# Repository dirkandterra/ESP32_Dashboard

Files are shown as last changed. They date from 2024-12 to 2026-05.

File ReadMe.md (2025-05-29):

# _ESP_Dashboard_  

_This project uses the a CANBus and an ESP32 to drive a 2004 Dodge Intrepid Dashboard._

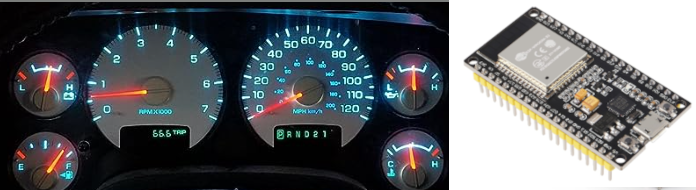
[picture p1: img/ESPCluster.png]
  

## How to use  

### Hardware Required  
* 2004 Dodge Intrepid Instrument Panel
* Connection:  

| Signal | Intrepid  | ESP32 |
|---|---|---|
| 5V | 5V		|  5V |
| GLDATA | GLDATA	|  D13  |
| GLCLK | GLCLK 	|  D14  |
| LightLatch| LightLatch|  D6 |
| Gauge CS  | Gauge CS  |  D7 |
| VFDDATA | VFDDATA |  D13  |
| VFDCLK	| VFDCLK	|  D14  |
| VFD Pls	| VFD Pls	|  D12  |
| Backlight | UC_LMP_DRV|  D15  |
| PB Input  | ODO PB |  D0 |
| L Turn | C2-5		|  D21  |
| R Turn | C1-8 |  D22  |
| HighBeam  | C1-10 |  D23  |
| OilPress  | C2-10 |  D2 |
| ABS		| ??		|  D18  |
| Airbag | ??		|  D19  |
| GND | GND |  GND  |
| CAN TX |			|  D5	|
| CAN RX	|			|  D4	|

### Arduino Library Needed  

```
https://github.com/coryjfowler/MCP_CAN_lib.git
```

* MCP_CAN_lib

### Intrepid Dashboard Help

* Board Files:
Board_Files 

* Intrepid Schematic (Not Complete):  

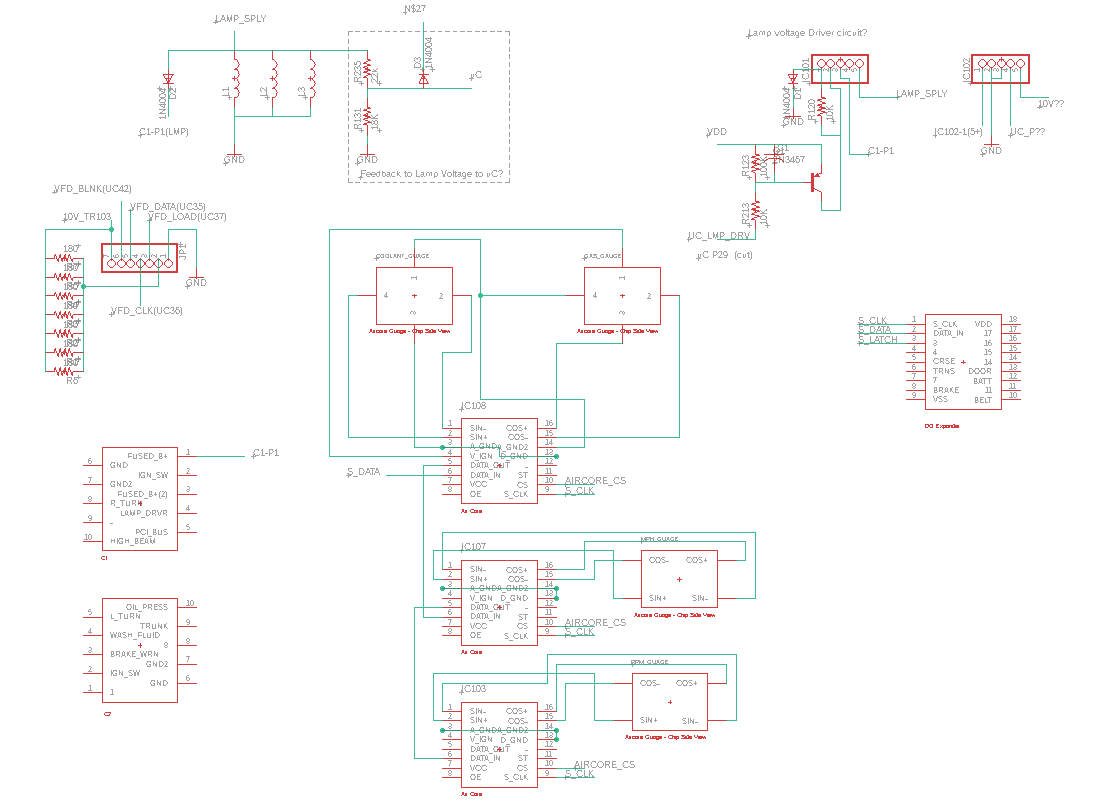
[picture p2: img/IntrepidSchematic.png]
IntrepidSchematic


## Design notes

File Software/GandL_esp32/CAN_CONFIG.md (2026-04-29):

# CAN Bus Gauge & VFD Configuration

Settings for each channel are stored in EEPROM and sent over the USB serial port (115200 baud). Switch the dashboard to **CAN mode** by pressing the mode button until the VFD shows `CAN`.

---

## Channel Assignments

| Channel | Output |
|---|---|
| 0 | Gauge 0 (e.g. RPM) |
| 1 | Gauge 1 (e.g. MPH) |
| 2 | Gauge 2 (e.g. Fuel) |
| 3 | Gauge 3 (e.g. Temp) |
| 4 | VFD numeric display |

---

## Config Fields

Each channel has six fields:

| Field | Size | Description |
|---|---|---|
| `PGN` | 3 bytes | Upper 3 bytes of the CAN ID (big-endian). Set a byte to `0xFF` to wildcard it. |
| `Source` | 1 byte | Lowest byte of the CAN ID (J1939 source address). Set to `0xFF` to match any. |
| `DataStart` | 1 byte | Index of the first data byte to read (0–7). |
| `DataLen` | 1 byte | Number of bytes to read (1–4). Data bytes are little-endian — `DataStart` is the LSB. |
| `Gain` | float | Multiplied against the raw extracted value. |
| `Offset` | float | Added after the gain multiplication. |

The final value sent to the gauge or VFD is:

```
result = raw * gain + offset
```

### Little-Endian Extraction

For a 2-byte signal at `DataStart=0` with frame bytes `[0xA0, 0x02, ...]`:

```
raw = 0xA0 + (0x02 << 8) = 0x02A0 = 672
```

---

## CAN ID Encoding

The four bytes `PGN[0]`, `PGN[1]`, `PGN[2]`, `Source` form a 32-bit CAN identifier (big-endian):

```
targetId = (PGN[0] << 24) | (PGN[1] << 16) | (PGN[2] << 8) | Source
```

**Standard 11-bit ID** (e.g. `0x1B0`):

```
PGN = 0001B0   src = FF
→ targetId = 0x000001B0 = 0x1B0  (source wildcarded)
```

**J1939 29-bit ID** (e.g. `0x18FEF100`):

```
PGN = 18FEF1   src = 00
→ targetId = 0x18FEF100
```

### Wildcards

Set any byte of PGN or src to `FF` to ignore it during matching.

```
PGN = 18FEF1   src = FF
→ matches 0x18FEF1xx (any source address)
```

---

## Serial Config Protocol

Send a comma-separated ASCII line terminated with `\r`. Works in any display mode.

```
C<ch>,<PGN>,<src>,<dataStart>,<dataLen>,<gain>,<offset>\r
```

- `PGN` — 6 hex digits (no prefix), upper-case or lower-case, e.g. `0000CF`
- `src` — 2 hex digits, e.g. `FF` for wildcard
- `dataStart`, `dataLen` — decimal integers
- `gain`, `offset` — floating point

```
C0,0000CF,FF,0,2,0.25,0.0\r
```

The device responds with a confirmation line, e.g.:

```
CFG ch0: PGN=0000CF src=FF dStart=0 dLen=2 gain=0.2500 off=0.0000
```

### Query a Channel

Send `Q` followed by the channel digit and `\r` to read back saved settings:

```
Q0\r   → prints channel 0 config
Q4\r   → prints channel 4 (VFD) config
```

---

## Examples

### RPM on ID 0x0CF, bytes 0–1 (little-endian)
Raw convention: `(byte1 << 8 | byte0) / 4 = RPM`

```
C0,0000CF,FF,0,2,0.25,0.0\r
```

### Vehicle Speed on ID 0x1B0, bytes 0–1 (little-endian)
Raw convention: `(byte1 << 8 | byte0) / 128 = MPH`

```
C1,0001B0,FF,0,2,0.0078125,0.0\r
```

### Coolant Temp on ID 0x1E4, byte 0 (single byte)
Raw convention: `byte0 - 40 = °C`, mapped to 0–100 gauge range (40–120 °C → 0–100%)

```
C3,0001E4,FF,0,1,1.25,-50.0\r
```

### VFD showing fuel level on ID 0x1E4, byte 1 (single byte)
Raw convention: 0–255 → 0–100%

```
C4,0001E4,FF,1,1,0.3922,0.0\r
```

---

## Discovering IDs

Set `CAN_SNIFF_MODE 1` in `CANDash.h` and monitor the serial output. Every received frame is printed:

```
CAN 0x000001B0 [8]: A0 02 00 00 00 00 00 00
```

This shows the full 32-bit identifier, data length, and all 8 data bytes in frame order (byte 0 first). Remember that multi-byte signals are little-endian — byte 0 is the LSB. In the example above, the 2-byte value at bytes 0–1 is `0x02A0 = 672`.

Set `CAN_SNIFF_MODE 0` when done to reduce serial traffic.

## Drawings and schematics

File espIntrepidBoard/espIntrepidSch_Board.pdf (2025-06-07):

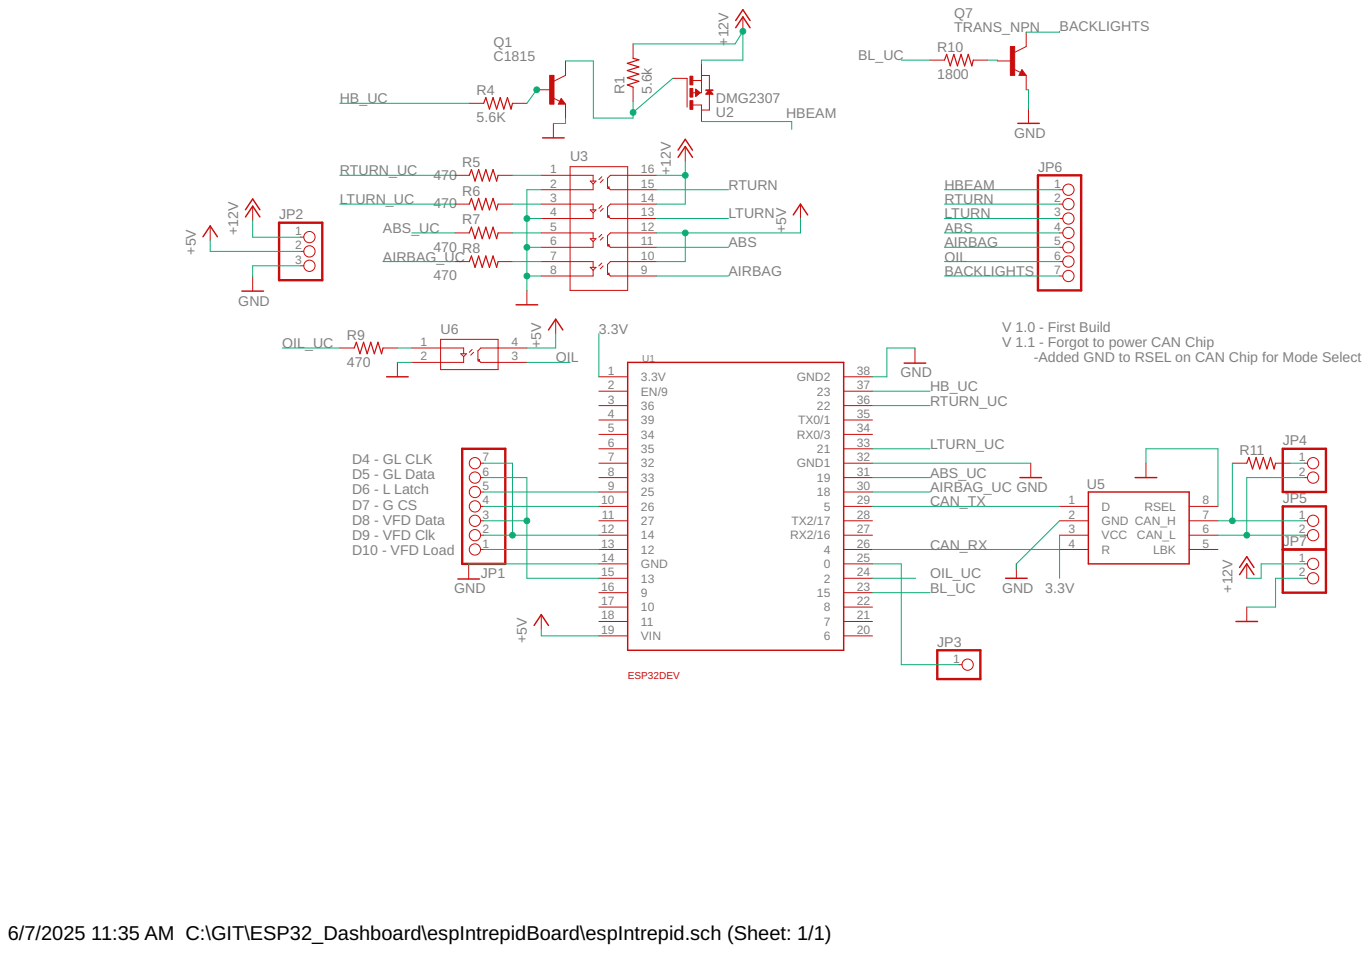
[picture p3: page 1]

V 1.0 - First Build
V 1.1 - Forgot to power CAN Chip
-Added GND to RSEL on CAN Chip for Mode Select

D8 - VFD Data D9 - VFD Clk

6/7/2025 11:35 AM C:\GIT\ESP32_Dashboard\espIntrepidBoard\espIntrepid.sch (Sheet: 1/1)

## ESP32_Dashboard

U1

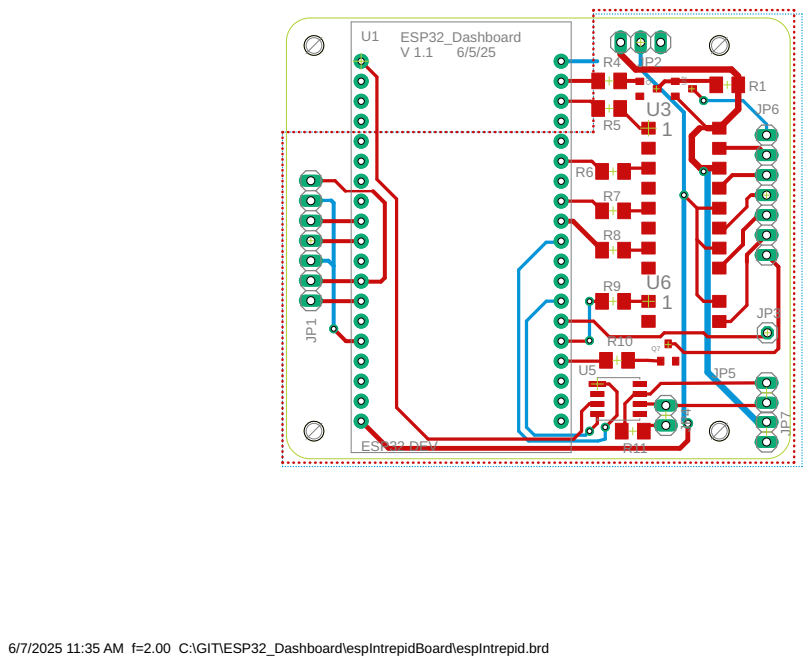
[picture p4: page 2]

6/7/2025 11:35 AM f=2.00 C:\GIT\ESP32_Dashboard\espIntrepidBoard\espIntrepid.brd

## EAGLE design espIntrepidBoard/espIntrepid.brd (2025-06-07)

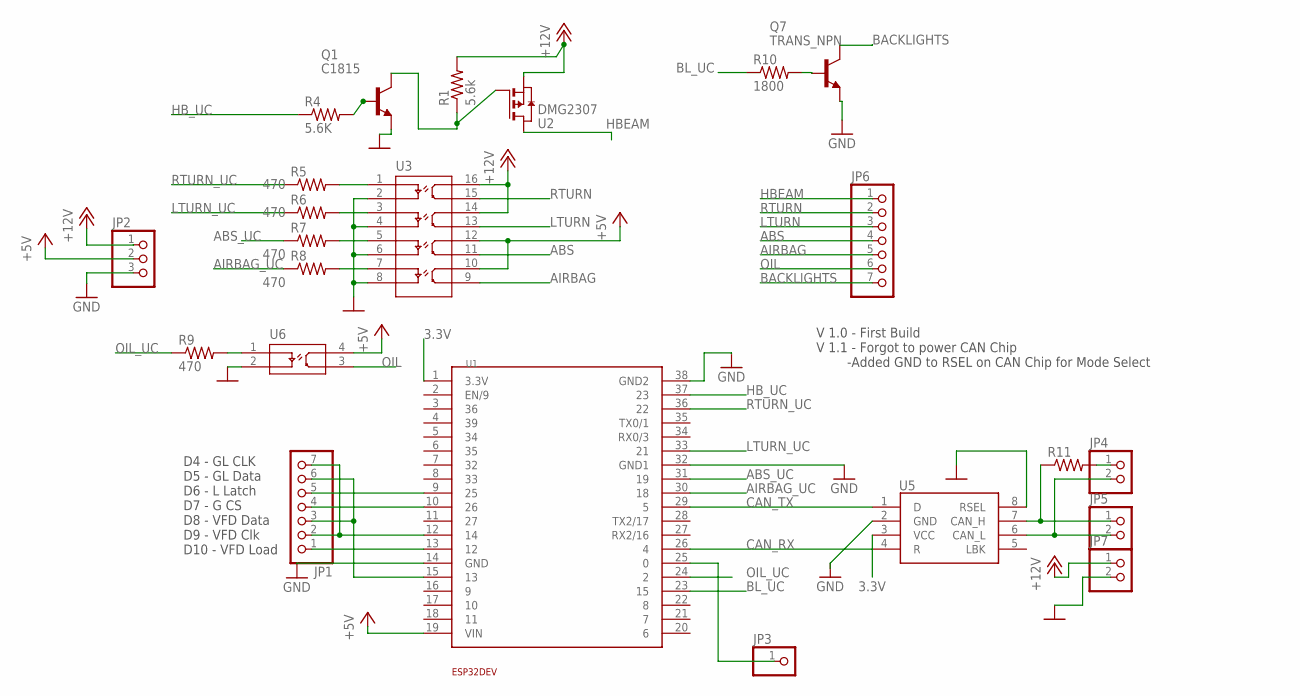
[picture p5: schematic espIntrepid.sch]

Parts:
JP1, JP6: PINHD-1X7; 1X07
JP2: PINHD-1X3; 1X03
JP3: PINHD-1X1; 1X01
JP4, JP5, JP7: PINHD-1X2; 1X02
Q1: C1815; SOT-23
Q7: TRANS_NPN; SOT-23
R1: 5.6k; M1206
R4: 5.6K; M1206
R5, R6, R7, R8, R9: 470; M1206
R10: 1800; M1206
R11: R-US_M1206; M1206
U1: ESP32DEV_38
U2: DMG2307; SOT-23
U3: LTV-847; SM-16
U5: SN65HVD233D; SOIC-8
U6: LTV-817; SM-4

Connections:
3.3V: U1.1 (3.3V), U5.3 (VCC)
+5V: JP2.2, U1.19 (VIN), U3.10, U3.12, U6.4
+12V: JP2.1, JP7.1, R1.2, U2.2 (S), U3.14, U3.16
ABS: JP6.4, U3.11
ABS_UC: R7.1, U1.31 (19)
AIRBAG: JP6.5, U3.9
AIRBAG_UC: R8.1, U1.30 (18)
BACKLIGHTS: JP6.7, Q7.3 (C)
BL_UC: R10.1, U1.23 (15)
CAN_RX: U1.26 (4), U5.4 (R)
CAN_TX: U1.29 (5), U5.1 (D)
GND: JP2.3, JP7.2, Q1.2 (E), Q7.2 (E), U1.14 (GND), U1.32 (GND1), U1.38 (GND2), U3.2, U3.4, U3.6, U3.8, U5.2 (GND), U5.8 (RSEL), U6.2
HBEAM: JP6.1, U2.3 (D)
HB_UC: R4.1, U1.37 (23)
LTURN: JP6.3, U3.13
LTURN_UC: R6.1, U1.33 (21)
unnamed: Q7.1 (B), R10.2
unnamed: R5.2, U3.1
unnamed: JP5.1, R11.1, U5.7 (CAN_H)
unnamed: JP1.5, U1.9 (25)
unnamed: JP1.4, U1.10 (26)
unnamed: JP1.1, U1.13 (12)
unnamed: JP1.3, JP1.6, U1.15 (13)
unnamed: JP1.2, JP1.7, U1.12 (14)
unnamed: R8.2, U3.7
unnamed: Q1.1 (B), R4.2
unnamed: Q1.3 (C), R1.1, U2.1 (G)
unnamed: R6.2, U3.3
unnamed: R7.2, U3.5
unnamed: R9.2, U6.1
unnamed: JP3.1, U1.25 (0)
unnamed: JP4.2, JP5.2, U5.6 (CAN_L)
unnamed: JP4.1, R11.2
OIL: JP6.6, U6.3
OIL_UC: R9.1, U1.24 (2)
RTURN: JP6.2, U3.15
RTURN_UC: R5.1, U1.36 (22)

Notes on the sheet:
D4 - GL CLK D5 - GL Data D6 - L Latch D7 - G CS D8 - VFD Data D9 - VFD Clk D10 - VFD Load
V 1.0 - First Build V 1.1 - Forgot to power CAN Chip -Added GND to RSEL on CAN Chip for Mode Select

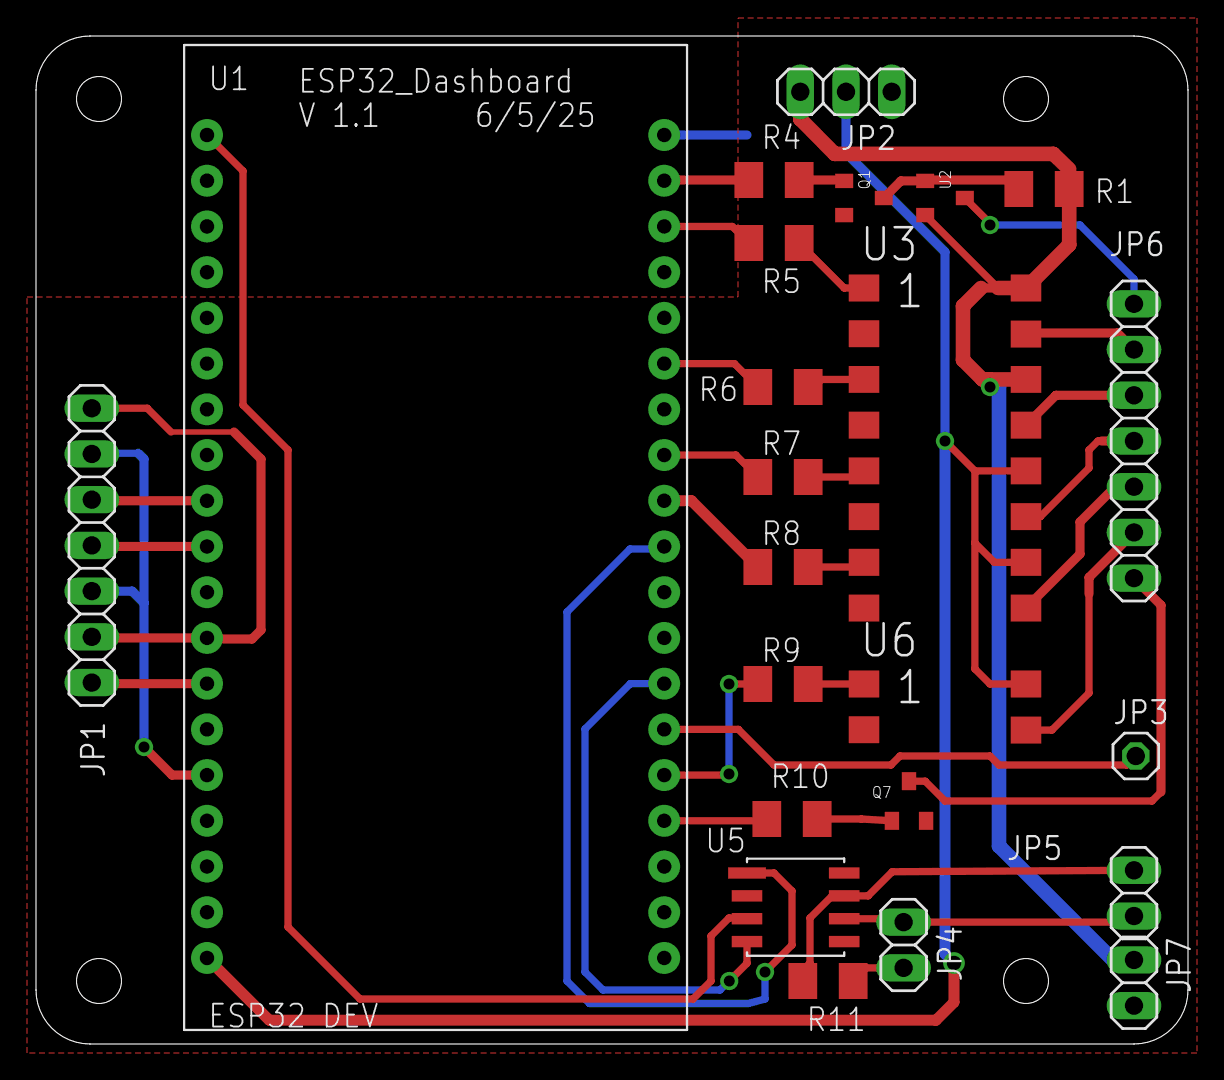
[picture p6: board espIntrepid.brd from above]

Board: 2 copper layers, 64.0 x 56.0 mm, 23 parts (0 on the bottom side), 37 nets.

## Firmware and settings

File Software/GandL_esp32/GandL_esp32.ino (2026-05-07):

//#include <avr/io.h>
#include "WIFI_MQTT.h"
#include "EE.h"
#include "GandL.h"
#include "IntrVFD.h"
#include "CANDash.h"

#define VER "1.00"

#define HBEAM   23
#define RTURN   22
#define LTURN   21
#define ABS     19
#define AIRBAG  18
#define OIL     2
#define BKLIGHT 15
#define PB      0

#define PB_DELAY 200
#define PB_LOCKOUT 500  //event triggered, delay before reading again
#define PB_LONGPUSH 1500/PB_DELAY   //Milliseconds divided by delay between reads
#define PB_PUSHED  0   //PB val is 0 when held

uint32_t timerGaugeAndLights=0;
uint32_t displayInfoUpdate;
uint32_t vfdLockoutTimer=0;
uint8_t vfdLockout=0;

uint32_t startupTest=1;
uint8_t backlight = 0;
typedef struct _pb{
  uint8_t currentRead;
  uint8_t lastRead;
  uint8_t holdCount;
  uint8_t pbEvent;  //0 is clear, 1 is short press, 2 is long press
  uint32_t pbTimer;
}pb_T;

typedef struct rxBuff{
  uint8_t data[50];
  uint8_t rxPtr;
}rxBuff;
rxBuff rx232;

pb_T pb;
boolean stringComplete=false;

void writeModeToVFD(uint32_t currentMillis);
void handle232(void);
void clearAll(uint8_t includeBacklight);
double del = 100000;

enum{
  PRESS_NONE,
  PRESS_SHORT,
  PRESS_LONG
};

void setup() {
  int ii=0;
  pb.lastRead = !PB_PUSHED;
  pinMode(HBEAM,OUTPUT);
  pinMode(RTURN,OUTPUT);
  pinMode(LTURN,OUTPUT);
  pinMode(AIRBAG,OUTPUT);
  pinMode(ABS,OUTPUT);
  pinMode(OIL,OUTPUT);
  pinMode(BKLIGHT,OUTPUT);
  pinMode(PB,INPUT);

  DecodeInit();

  Serial.begin(115200);
  EEPROM.begin(sizeof(EE));
  rx232.rxPtr=0;
  Serial.println("Starting...");
  startupTest=millis()+5000;
  sendInfo(0, 700);
  sendInfo(1, 1200);
  sendInfo(2, 100);
  sendInfo(3, 100);
  sendInfo(4, 0xFFFF);
  digitalWrite(HBEAM,1);
  digitalWrite(RTURN,1);
  digitalWrite(LTURN,1);
  digitalWrite(ABS,1);
  digitalWrite(AIRBAG,1);
  digitalWrite(OIL,1);
  digitalWrite(BKLIGHT,1);
  printTextToVFD("888888",0,6,J_LEFT,vfd);
  setVfdExtra(vfdAll,1);
  setVFDDimming(0x02);
  sendVFD(vfd);
  init_EEVars();
  setup_WIFI();
  setup_MQTT();
  CANInit();
}

void loop() {
  uint32_t loopMillis = millis();
  checkMQTTConnection(loopMillis);

  if(vfdLockoutTimer<loopMillis){
    vfdLockout=false;
  }
  if(loopMillis>pb.pbTimer){
    //time to read pb
    pb.pbTimer=loopMillis+PB_DELAY;
    pb.currentRead = digitalRead(PB);
    if(pb.currentRead == !PB_PUSHED){
      //button is up
      if(pb.currentRead != pb.lastRead){
        //pb has been released
        pb.holdCount=0;
        pb.pbTimer=loopMillis+PB_LOCKOUT;
        pb.pbEvent=PRESS_SHORT;
        Serial.println("Short");
      }  
    }else{
      //button is down
      pb.holdCount++;
      if(pb.holdCount>=PB_LONGPUSH){
        //Longpress event
        pb.holdCount=0;
        pb.currentRead = !PB_PUSHED;
        pb.pbTimer=loopMillis+PB_LOCKOUT;
        pb.pbEvent=PRESS_LONG;
        Serial.println("Long");
      }
    }
    pb.lastRead=pb.currentRead;
    if(pb.pbEvent==PRESS_LONG){
      backlight=!backlight;
      digitalWrite(BKLIGHT,backlight);
    }else if(pb.pbEvent==PRESS_SHORT){
      GaugeMode++;
      if(GaugeMode>=GMODE_END){
        GaugeMode=0;
      }
      EE.gaugeMode = GaugeMode;
      Save_GaugeMode();
      writeModeToVFD(loopMillis);
      Serial.println(GaugeMode);
      
    }
    pb.pbEvent=PRESS_NONE;
  }
  if(loopMillis>displayInfoUpdate){
    switch(GaugeMode){
      case GMODE_SERIAL:
      default:
        if(stringComplete){
          stringComplete=false;
          handle232();
        }
        displayInfoUpdate=loopMillis+200;
        break;
      case GMODE_WEATHER:
        vfdWeatherPrep();
        if(!vfdLockout){
          sendVFD(vfd);
        }
        displayInfoUpdate=loopMillis+2000;
        break;
      case GMODE_TSTAT:
        sendInfo(1, ServerData.garageTemp*10);
        displayInfoUpdate=loopMillis+2000;
        break;
      case GMODE_CAN:
        CANProcess(EE.chanCfg, NUM_CHANNELS);
        for (uint8_t ch = 0; ch < 4; ch++) {
          if (canData.ch[ch].updated) {
            sendInfo(ch, (uint16_t)canData.ch[ch].val);
            canData.ch[ch].updated = 0;
          }
        }
        if (!vfdLockout && canData.ch[NUM_CHANNELS-1].valid) {
          printNumToVFD((uint16_t)canData.ch[NUM_CHANNELS-1].val, 0, 6, 0, J_RIGHT, vfd);
          sendVFD(vfd);
        }
        displayInfoUpdate = loopMillis + 200;
        break;
    }    
  }
  if(loopMillis>timerGaugeAndLights){
    timerGaugeAndLights=loopMillis+50;
    updateGuages_Lights();
  }
  //#################only runs once after bootup###############
  if((loopMillis>startupTest) && startupTest>0){
    startupTest=0;  //one time only
    clearAll(1);
    writeModeToVFD(loopMillis);
  }
}

void serialEvent() {
  while (Serial.available()) {
    uint8_t inByte = (uint8_t)Serial.read();
    if(inByte == '\r'){
      // Config commands work in any mode; gauge commands only in GMODE_SERIAL
      if(rx232.data[0] == 'C' || rx232.data[0] == 'Q' || GaugeMode == GMODE_SERIAL){
        stringComplete = true;
      } else {
        rx232.rxPtr = 0;
      }
    } else if(inByte != '\n'){
      if(rx232.rxPtr < sizeof(rx232.data) - 1){
        rx232.data[rx232.rxPtr++] = inByte;
      }
    }
  }
}

void handle232(){
  uint8_t dataLength=rx232.rxPtr;
  uint16_t multiplier=1, temp16=0;
  if(dataLength==1){
    rx232.data[1]='0';
  }
  switch(rx232.data[0]){
    case '0':
      dataLength-=1;   //Don't count the first byte identifier
      for(int ii=dataLength; ii>0; ii--){
          temp16+=(rx232.data[ii]-0x30)*multiplier;
          multiplier*=10;
      }
      //Serial.println(temp16);  
      sendInfo(0, temp16);
      break;
    case '1':
      dataLength-=1;   //Don't count the first byte identifier
      for(int ii=dataLength; ii>0; ii--){
          temp16+=(rx232.data[ii]-0x30)*multiplier;
          multiplier*=10;
      }
      //Serial.println(temp16);  
      sendInfo(1, temp16);
      break;
    case '2':
      dataLength-=1;   //Don't count the first byte identifier
      for(int ii=dataLength; ii>0; ii--){
          temp16+=(rx232.data[ii]-0x30)*multiplier;
          multiplier*=10;
      }
      //Serial.println(temp16);  
      sendInfo(2, temp16);
      break;
    
  case '3':
      dataLength-=1;   //Don't count the first byte identifier
      for(int ii=dataLength; ii>0; ii--){
          temp16+=(rx232.data[ii]-0x30)*multiplier;
          multiplier*=10;
      }
      //Serial.println(temp16);  
      sendInfo(3, temp16);
      digitalWrite(HBEAM,0);
      digitalWrite(RTURN,0);
      digitalWrite(LTURN,1);
      digitalWrite(ABS,0);
      digitalWrite(AIRBAG,1);
      digitalWrite(OIL,0);
      digitalWrite(BKLIGHT,1);
      break;      
    case '4':
      dataLength-=1;   //Don't count the first byte identifier
      for(int ii=dataLength; ii>0; ii--){
          temp16+=(rx232.data[ii]-0x30)*multiplier;
          multiplier*=10;
      }
      //Serial.println(temp16);  
      sendInfo(4, temp16);
      digitalWrite(HBEAM,1);
      digitalWrite(RTURN,1);
      digitalWrite(LTURN,0);
      digitalWrite(ABS,1);
      digitalWrite(AIRBAG,0);
      digitalWrite(OIL,1);
      digitalWrite(BKLIGHT,0);
      break;
    case '5':
      dataLength-=1;   //Don't count the first byte identifier
      for(int ii=dataLength; ii>0; ii--){
          temp16+=(rx232.data[ii]-0x30)*multiplier;
          multiplier*=10;
      }
      testVFD(temp16);
      break;
    case '6':
      dataLength-=1;   //Don't count the first byte identifier 
      if(!vfdLockout){
        sendVFD(rx232.data);
      }
      break;

    case '7':
      dataLength-=1;   //Don't count the first byte identifier
      for(int ii=dataLength; ii>0; ii--){
          temp16+=(rx232.data[ii]-0x30)*multiplier;
          multiplier*=10;
      }
      rx232.data[8]|=0x80;
      rx232.data[5]=rx232.data[4];
      rx232.data[4]=rx232.data[3];
      rx232.data[3]=rx232.data[2];
      rx232.data[2]=rx232.data[1];
      rx232.data[0]=' ';  
      rx232.data[1]=' ';  
      //Serial.println(temp16);  
      sendInfo(1, temp16);
      printTextToVFD((char *)rx232.data,0,6,J_LEFT,vfd);
      if(!vfdLockout){
        sendVFD(rx232.data);
      }
      break;

    case '8':
      dataLength-=1;   //Don't count the first byte identifier 
      printTextToVFD("L",0,2,J_LEFT,vfd);
      printNumToVFD(1013,2,4,1,J_RIGHT,vfd);
      if(!vfdLockout){
        sendVFD(rx232.data);
      }
      break;
    case '9':
      if(rx232.data[1]<0x30){
        rx232.data[1]='0';
      }
      rx232.data[1]-=0x30;
      setVFDDimming(0x01*rx232.data[1]);
      break;
    case 'A':
      sendInfo(5,232);
      break;
    case 'B':
      sendInfo(5,590);
      break;
    case 'Z':
      clearAll(1);
      break;
    case 'v':
    case 'V':
      Serial.println(VER);
      break;
    case 'C': {
      rx232.data[rx232.rxPtr] = '\0';
      char *tok = strtok((char*)&rx232.data[1], ",");
      if(!tok) break;
      uint8_t ch = (uint8_t)atoi(tok);
      if(ch >= NUM_CHANNELS){ Serial.println("CFG: bad channel"); break; }
      ChanConfig_t *cfg = &EE.chanCfg[ch];
      if((tok = strtok(NULL, ","))) {
        uint32_t pgn = strtoul(tok, NULL, 16);
        cfg->pgn[0] = (pgn >> 16) & 0xFF;
        cfg->pgn[1] = (pgn >>  8) & 0xFF;
        cfg->pgn[2] =  pgn        & 0xFF;
      }
      if((tok = strtok(NULL, ","))) cfg->source    = (uint8_t)strtoul(tok, NULL, 16);
      if((tok = strtok(NULL, ","))) cfg->dataStart = (uint8_t)atoi(tok);
      if((tok = strtok(NULL, ","))) cfg->dataLen   = (uint8_t)atoi(tok);
      if((tok = strtok(NULL, ","))) cfg->gain      = atof(tok);
      if((tok = strtok(NULL, ","))) cfg->offset    = atof(tok);
      Save_CANChan(cfg);
      Serial.printf("CFG ch%d: PGN=%02X%02X%02X src=%02X dStart=%d dLen=%d gain=%.4f off=%.4f\r\n",
        ch, cfg->pgn[0], cfg->pgn[1], cfg->pgn[2],
        cfg->source, cfg->dataStart, cfg->dataLen,
        cfg->gain, cfg->offset);
      break;
    }
    case 'Q': {
      uint8_t ch = (dataLength > 1) ? (rx232.data[1] - '0') : 0;
      if(ch < NUM_CHANNELS){
        ChanConfig_t *cfg = &EE.chanCfg[ch];
        Serial.printf("ch%d: PGN=%02X%02X%02X src=%02X dStart=%d dLen=%d gain=%.4f off=%.4f\r\n",
          ch, cfg->pgn[0], cfg->pgn[1], cfg->pgn[2],
          cfg->source, cfg->dataStart, cfg->dataLen,
          cfg->gain, cfg->offset);
      }
      break;
    }
    default:
      break;
      
    
  }
  
  rx232.rxPtr=0;

}

void clearAll(uint8_t includeBacklight){
  sendInfo(0, 0);
  sendInfo(1, 0);
  sendInfo(2, 0);
  sendInfo(3, 0);
  sendInfo(4, 0x0);
  digitalWrite(HBEAM,0);
  digitalWrite(RTURN,0);
  digitalWrite(LTURN,0);
  digitalWrite(ABS,0);
  digitalWrite(AIRBAG,0);
  digitalWrite(OIL,0);
  if(includeBacklight){
    digitalWrite(BKLIGHT,0);
  }
  printTextToVFD("      ",0,6,J_LEFT,vfd);
  setVfdExtra(vfdAll,0);
  setVFDDimming(0x02);
  sendVFD(vfd);
}

void writeModeToVFD(uint32_t currentMillis){
  clearAll(0);
  switch(GaugeMode){
    default:
    case GMODE_SERIAL:
	  printTextToVFD("SERIAL",0,6,J_LEFT,vfd);
	  break;
    case GMODE_WEATHER:
	  printTextToVFD("WEATHR",0,6,J_LEFT,vfd);
	  break;
    case GMODE_TSTAT:
	  printTextToVFD("TSTAT ",0,6,J_LEFT,vfd);
	  break;
    case GMODE_CAN:
	  printTextToVFD("CAN   ",0,6,J_LEFT,vfd);
	  break;
  }
      setVFDDimming(0x02);
  sendVFD(vfd);
  vfdLockoutTimer=currentMillis+3000;  //Let the display show the mode for 3 seconds before changing
  vfdLockout=true;
}

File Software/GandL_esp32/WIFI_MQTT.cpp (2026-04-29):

//WIFI_MQTT
//-_-_-_-_-_-_-_-_-_-_-_-_-_-_-_-_-_-_-_-_-_-_-_-_-_-_-_-_
#include "WIFI_MQTT.h"
#include "EE.h"

uint32_t retryTimeMQTT=0;
WiFiClient IntrepidDash;
PubSubClient client(IntrepidDash);
WiFiServer TelnetServer(8266);
char IPAddr[17]="0.0.0.0";
NodeRedData ServerData = {0,0,0,0,0,0,0,0,0,0,0,0};
IPAddress IP;
String SSIDName="";
//*WIFI STUFF*
// Replace with your network credentials
const char* ssidAP     = WIFI_SSID;
const char* passwordAP = WIFI_PWD;
void callbackMQTT(String topic, byte* message, unsigned int length);

void setup_MQTT(void){
  client.setServer(MQTT_SERVER, 1883);
  client.setCallback(callbackMQTT);
}

void setup_WIFI(){ 
  // Connect to Wi-Fi
  int storedWifiRetry=20;
  WiFi.begin(EE.ssid, EE.pwd);
  while ((WiFi.status() != WL_CONNECTED) && (storedWifiRetry>0)) {
    delay(500);
    Serial.print(".");
    storedWifiRetry--;
  }
  if(storedWifiRetry){
      Serial.println("");
      Serial.println("WiFi connected.");
      Serial.println("IP address: ");
      SSIDName=EE.ssid;
      IP = WiFi.localIP();
      Serial.println(IP);
  }
  else{
    Serial.println("WiFi Failed on " + String(EE.ssid) + "!");
    WiFi.softAP(ssidAP, passwordAP);
    IP = WiFi.softAPIP();
    SSIDName=ssidAP;
    Serial.print("AP IP address: ");
    Serial.println(IP);
  } 
}
// ################ MQTT ROUTINES ##################

// This functions connects your ESP8266 to your MQTT broker
void checkMQTTConnection(uint32_t now) {
  // Try to reconnect every 20 sec if not connected or timed out
  if (!client.connected() || !client.loop()){
    if ((now>retryTimeMQTT) || retryTimeMQTT==0){
      retryTimeMQTT=now+20000;
      Serial.print("Attempting MQTT connection...");
      // Attempt to connect
      if (client.connect("IntrepidEsp32",MOSQUITTO_USR,MOSQUITTO_PWD)) {
        Serial.println("connected");
        // Subscribe or resubscribe to a topic
        // You can subscribe to more topics (to control more LEDs in this example)
        client.subscribe("intrESP32/forecast");
        client.subscribe("esp32/GarageTemp");
      } else {
        Serial.print("failed, rc=");
        Serial.print(client.state());
        Serial.println(" try again in 20 seconds");
      }
    }
  }
}
// This functions is executed when some device publishes a message to a topic that your ESP8266 is subscribed to
// check the topic and handle the message
void callbackMQTT(String topic, byte* message, unsigned int length) {
  Serial.print("Message arrived on topic: ");
  Serial.print(topic);
  Serial.print(". Message: ");
  String messageTemp;
  char *token;
  char data[100];
  uint8_t *ptr8;
  int i=0;
  
  for (i = 0; i < length; i++) {
    Serial.print((char)message[i]);
    messageTemp += (char)message[i];
  }
  Serial.println();
  if(topic=="esp32/GarageTemp"){
    ServerData.garageTemp=(uint16_t)round(messageTemp.toFloat());
    Serial.println(ServerData.currentTemp);
  }
  if(topic=="intrESP32/forecast"){
    messageTemp.toCharArray(data, messageTemp.length()+1);
    token = strtok(data, ","); // Get the first token
    if (token != NULL) {
      ServerData.currentTemp = (uint16_t)round(atof(token)*10); // Convert the token to a float
    }
    token = strtok(NULL, ","); // Get the next
    if (token != NULL) {
      ServerData.currentWind = (uint16_t)round(atof(token)); // Convert the token to a float
    }
    ptr8=ServerData.forecast;
    for(i=0;i<10;i++){
      token = strtok(NULL, ","); // Get the next
      if (token != NULL) {
        *ptr8 = (uint8_t)round(atof(token)); // Convert the token to a float
      }
      ptr8++;
    }
    token = strtok(NULL, ","); // Get the next
    if (token != NULL) {
      ServerData.precipPercent = (uint8_t)round(atof(token)); // Convert the token to a float
    }

  }
}

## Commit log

2024-12-11 First Upload switching from nano
    Changed board to ESP32
    [MCP2515Calc.xlsx, espIntrepid.brd, espIntrepid.sch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]
2024-12-11 removed unneeded nano mcp2515 files
    [MCP2515Calc.xlsx]
2024-12-15 Started board routing
    [espIntrepid.brd, espIntrepid.sch]
2025-02-10 Using optoisolators
    [espIntrepid.brd, espIntrepid.sch]
2025-02-11 Still need to test but board finished
2025-02-11 Created esp32 arduino program
    [espIntrepid.brd, espIntrepid.sch]
2025-02-11 Added SPI routines to handle Guage,vfd, and lights
2025-02-11 Made improvements to board (small stuff)
    [espIntrepid.brd, espIntrepid.sch]
2025-02-12 SPI working
2025-02-15 Update RS232Decode.cpp, gauge routine had an error
    [RS232Decode.cpp]
2025-02-15 All functioning with ESP32, just trying to get rid of the 'ticking' bug from the guages
    [RS232Decode.cpp]
2025-02-15 Software is fully functional. Lights need SPI Mode1 (clock falling edge) Guage and VFD need Mode0 (clock rising edge)
2025-02-17 Finished board
    [espIntrepid.brd, espIntrepid.sch]
2025-06-06 Made fixes to board, started V1.1
    [espIntrepid.brd, espIntrepid.sch]
2025-06-07 -Swapped 2 pins on board -Added reverse engg schematic
    [IntrepidDashboard.sch, espIntrepid.brd, espIntrepid.sch]
2026-04-29 Found an issue with glitchy VFD, had to do with sending vfd dimming
    [GandL_esp32.ino, RS232Decode.h]
2026-05-02 Display blanking out almost fixed
    [GandL_esp32.ino]
2026-05-02 testing VFD and tick issue
    [GandL_esp32.ino, RS232Decode.cpp, RS232Decode.h]
